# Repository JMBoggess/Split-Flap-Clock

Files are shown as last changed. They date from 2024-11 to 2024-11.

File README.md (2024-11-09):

# Split-Flap-Clock
Clock using a split-flap display

# Background
In December 2023, I bought my first microcontroller. I first began working on a similar project using a split-flap display to show number of instagram followers which I began in February 2024. I began this project in November 2024 seeking to build on what I learned through the previous project. The goal of this project is to create a split-flap display clock with a self-setting time feature. I will be using a Raspberry Pi Pico W microcontroller and 3D printed split-flap displays.

# Components

## 14-Flap Split-Flap Display
The split-flap displays were designed primarily from [Scott Bezek's work](https://github.com/scottbez1/splitflap). My primary alteration is a 14-flap version since I am primarily interested in displaying numbers. I found 14 flaps was a good compromise in reducing the overall dimensions while leaving enough room for certain components (e.g. magnet in the spool section for the Hall sensor). The overall dimensions of each display is:
- Width: 90mm
- Height: 133mm
- Depth: 60mm

## Split-Flap Electronics
- Shift-bit Register (2) - used with the four digit displays
- 28BYJ-48 Stepper Motors (5)
- Driver Boards (5)
- Hall Monitors (5)

## LED
Used to indicate program status
- 1 LED
- 220 Ohm resistor

## Buttons
Allows user to interact with the clock
- 2 buttons
  - Control Configuration mode
  - Manually run NTP Time Update mode

## Slide Switch
Used as an on/off switch

# Source Code

## Events

| Event | Description |
| --- | --- |
| Startup | When the clock is turned on, program execution begins. If enabled in configuration, NTP Time Update mode is executed. Display Update mode is then executed. |
| Config Button Click | A short button press places the clock in Configuration mode. A long button press exits configuration mode. Configuration mode can also be exited in the website |
| Set Date Time Click | A short button press manually starts the Set Date Time mode. A long button press cancels this mode. |
| Set Date Time Timer | Every hour, the clock automatically starts the Set Date Time mode. |

## Modes

### Configuration Mode
The clock is set as an Access Point (AP) allowing users to connect using wi-fi. The user connects with a web browser allowing them to perform the following actions:
- Setup wi-fi connection allowing the clock to connect to their home wi-fi for internet access to set the date and time
- Manually set the date and time of the clock
- View log files for troubleshooting issues
- Exit configuration mode

### Set Date Time Mode
If configured, the clock connects to the internet and updates the date and time using the [Network Time Protocol](https://en.wikipedia.org/wiki/Network_Time_Protocol) (NTP). The clock then runs the Display Update mode.
- This mode will automatically run every hour.
- Users can also click a button to run this mode at any time.

### Display Update Mode
The clock updates the split-flap displays to show the date and time. This mode executes:
- Automatically every minute
- After manually setting the date and time in Configuration mode
- The last step of the Set Date Time mode

## LED Indicator

| Light | Description |
| --- | --- |
| Solid On | The clock is in Set Date Time mode |
| Steady Blinking | The clock is in Configuration mode |
| Four-Pulse Rapid Blinking | An error occurred, view the log for details. The light blinks rapidly four times with a pause and then repeats several times before shutting off |

## Note about Chat GPT
I did not use Chat GPT or any other generative AI (GenAI) to produce any of the code. While I am not opposed to the use of GenAI as a programer, I believe it should be used as a supplemental reference and not in place of learning how to program.

# Notes
- TODO: Determine how to make the program start on power-up

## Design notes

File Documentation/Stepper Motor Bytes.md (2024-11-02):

# Stepper Motor Bytes
Turning a stepper motor effectively involves setting the polarity of two magnets. This is done by turning on or off four poles. There is a sequence of four steps in changing these polarities which results in turning the motor. These four on/off settings can be expressed in binary as follows.

| 8 | 4 | 2 | 1 | Integer | Step |
| --- | --- | --- | --- | --- | --- |
| 0 | 0 | 1 | 1 | 3 | 1 |
| 0 | 1 | 1 | 0 | 6 | 2 |
| 1 | 1 | 0 | 0 | 12 | 3 |
| 1 | 0 | 0 | 1 | 9 | 4 |

For the split-flap display, the motor needs to be run in reverse sequence: `9 > 12 > 6 > 3`. 74HC595 Shift Registers are used to control two split-flap displays. The Shift Regsiters are daisy chained to reduce the number of GPIO pins used on the Raspberry Pi Pico W. These Shift Registers output 8-bit information. With each step, both split-flap displays may or may not need to be moved forward. To determine the byte (8-bit) to send to each Shift Register, the following table was used to derive sequence numbers. A display which does not need to move is denoted with a zero in the Step column.

| 128 | 64 | 32 | 16 | 8 | 4 | 2 | 1 | Integer | Display 1 Step | Display 2 Step |
| --- | --- | --- | --- | --- | --- | --- | --- | --- | --- | --- |
| 1 | 0 | 0 | 1 | 1 | 0 | 0 | 1 | 153 | 4 | 4 |
| 1 | 1 | 0 | 0 | 1 | 1 | 0 | 0 | 204 | 3 | 3 |
| 0 | 1 | 1 | 0 | 0 | 1 | 1 | 0 | 102 | 2 | 2 |
| 0 | 0 | 1 | 1 | 0 | 0 | 1 | 1 | 51 | 1 | 1 |
| 1 | 0 | 0 | 1 | 0 | 0 | 0 | 0 | 144 | 4 | 0 |
| 1 | 1 | 0 | 0 | 0 | 0 | 0 | 0 | 192 | 3 | 0 |
| 0 | 1 | 1 | 0 | 0 | 0 | 0 | 0 | 96 | 2 | 0 |
| 0 | 0 | 1 | 1 | 0 | 0 | 0 | 0 | 48 | 1 | 0 |
| 0 | 0 | 0 | 0 | 1 | 0 | 0 | 1 | 9 | 0 | 4 |
| 0 | 0 | 0 | 0 | 1 | 1 | 0 | 0 | 12 | 0 | 3 |
| 0 | 0 | 0 | 0 | 0 | 1 | 1 | 0 | 6 | 0 | 2 |
| 0 | 0 | 0 | 0 | 0 | 0 | 1 | 1 | 3 | 0 | 1 |

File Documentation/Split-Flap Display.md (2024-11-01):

# Split-Flap Displays
The split-flap displays were designed primarily from [Scott Bezek's work](https://github.com/scottbez1/splitflap).

## Overall Dimensions
A single display has the following dimensions:
- Width: 90mm
  - 3D Printed Box: 69mm
- Height: 133mm
- Depth: 60mm
  - An additional 5-15mm is needed for wire management

## 14 Flaps
The original display by Scott Bezek contains 40 flaps. I chose to reduce this as I am primarily interested in display digits. Reducing the number of flaps reduces the dimensions of various parts. In order to retain enough space for some components (such as the magnet used by the Hall sensor), I found I needed a minimum of 14 flaps.

The 14 Flaps for the primary clock display include:
- Digits 0-9
- Comma `,`
- Semicolon `:`
- Exclamation Mark `!`
- Blank

A single 14-flap display is also used for day-of-week and time-of-day, including:
- Sun - Sat displayed on the top
- AM or PM displayed on the bottom

## 3D Printed Components

### Dimensions
Unless otherwise specified, all components were made to be 3mm thick.

- Top: 42mm x 69mm
  - Includes insert tabs (3mm on either side): 69mm - 6mm = 63mm
  - Includes two vertical screw-hole tabs for attaching to a face plate
    - These are both 10mm x 10mm
    - Component overall height is 13mm (3mm thickness + 10mm tabs)
- Base: 52mm x 69mm
  - Includes insert tabs (3mm on either side): 69mm - 6mm = 63mm
  - Includes two screw-hole tabs for attaching to a base
    - Both are 10mm x 10mm
    - 52mm - 10mm = 42mm
- Left Side: 42mm x 126mm
  - Motor hole center:
    - 9mm from edge
    - 63mm from bottom
- Right Side: 42mm x 126mm
  - Hole for spindle (opposite motor) same as Left Side (9mm from edge; 63mm from bottom)
  - Bottom flap restraint: begins 12mm from bottom, 4mm from either side
- Spool Left: 31mm diameter
  - Flap holes center: 9mm from center (2.5mm diameter)
- Spool Right: 31mm diameter
  - Flap holes center: 9mm from center (2.5mm diameter)
  - Magnet hole for Hall sensor: 12.5mm from center (3.2mm diameter)
    - Flap "0" should be located directly across from this hole
- Spool Box: 4 parts - 5mm x 55mm each
  - 2mm thick
  - Used for stability and assembly
- Axel Holder: 7mm x 7mm
  - 3.2mm thick
  - Used on right-side to hold axel screw (opposite motor)
- Face: 69mm x 30mm
  - This piece was used for testing, final wood box will act as face
  - Distance between holes: 31.5mm

In addition to the above components, I 3D printed a series of jigs
- Jig Flap Split: 60mm x 46mm
  - Used to score/cut cards in half to make flaps
  - 1mm thick lip 3mm wide to create a ledge against which the cards are placed
  - Results in flaps 43mm heigh (46mm - 3mm ledge)
- Jig Flap Hole: 40mm x 29mm
  - L-shaped jig, placed on the edge of a flap against which the hole punch is placed to cut the slot in the flap
- Jig Flap Hold: 37mm diameter
  - Used to hold flap cards in place while assemblying the spool
  - 33mm internal diameter

### Development
- I used OpenSCAD v2021.01 for 3D modeling
- STL files were then exported from OpenSCAD
- Creality Slicer v4.8.2 was used to encode the STL file to GCODE for the 3D printer
  - Some components were combined for printing into a single GCODE file
  - To create files:
    - Open STL file(s)
    - If desired, duplicate components (right-click)
    - Click Slice button
    - Red areas indicate problems (where model needs support)
    - Save the file as a GCODE file
    - Copy to sd card to load to Ender printer

### Card Layout
The following table depicts the card layout for the digits and day-of-week (DOW) and time-of-day (TOD) display.
- Flap - The visible flap displayed to the user (consists of different cards making up the Top and Bottom of the display)

| Flap | Position | Card | Digits | DOW/TOD |
| --- | --- | --- | --- | --- |
| 1 | Top | 1 | 0 | SUN |
| 1 | Bottom | 14 | 0 | AM |
| 2 | Top | 2 | 1 | SUN |
| 2 | Bottom | 1 | 1 | PM |
| 3 | Top | 3 | 2 | MON |
| 3 | Bottom | 2 | 2 | AM |
| 4 | Top | 4 | 3 | MON |
| 4 | Bottom | 3 | 3 | PM |
| 5 | Top | 5 | 4 | TUE |
| 5 | Bottom | 4 | 4 | AM |
| 6 | Top | 6 | 5 | TUE |
| 6 | Bottom | 5 | 5 | PM |
| 7 | Top | 7 | 6 | WED |
| 7 | Bottom | 6 | 6 | AM |
| 8 | Top | 8 | 7 | WED |
| 8 | Bottom | 7 | 7 | PM |
| 9 | Top | 9 | 8 | THU |
| 9 | Bottom | 8 | 8 | AM |
| 10 | Top | 10 | 9 | THU |
| 10 | Bottom | 9 | 9 | PM |
| 11 | Top | 11 |  | FRI |
| 11 | Bottom | 10 | , | AM |
| 12 | Top | 12 | : | FRI |
| 12 | Bottom | 11 | : | PM |
| 13 | Top | 13 | ! | SAT |
| 13 | Bottom | 12 | ! | AM |
| 14 | Top | 14 |  | SAT |
| 14 | Bottom | 13 |  | PM |

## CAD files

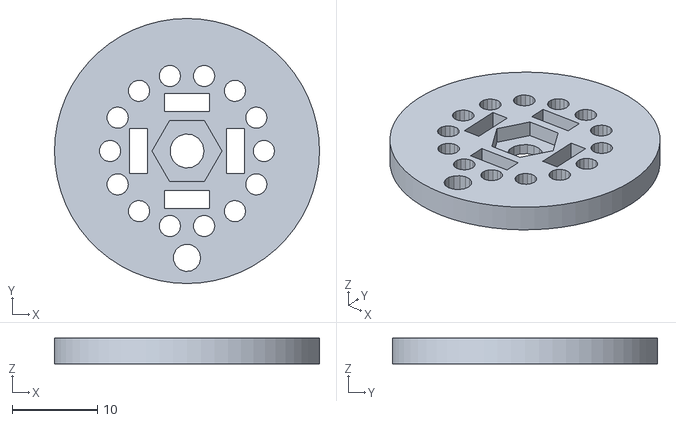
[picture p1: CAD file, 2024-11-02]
Split Flap/STL/spool-right.stl
31.0 x 31.0 x 3.00

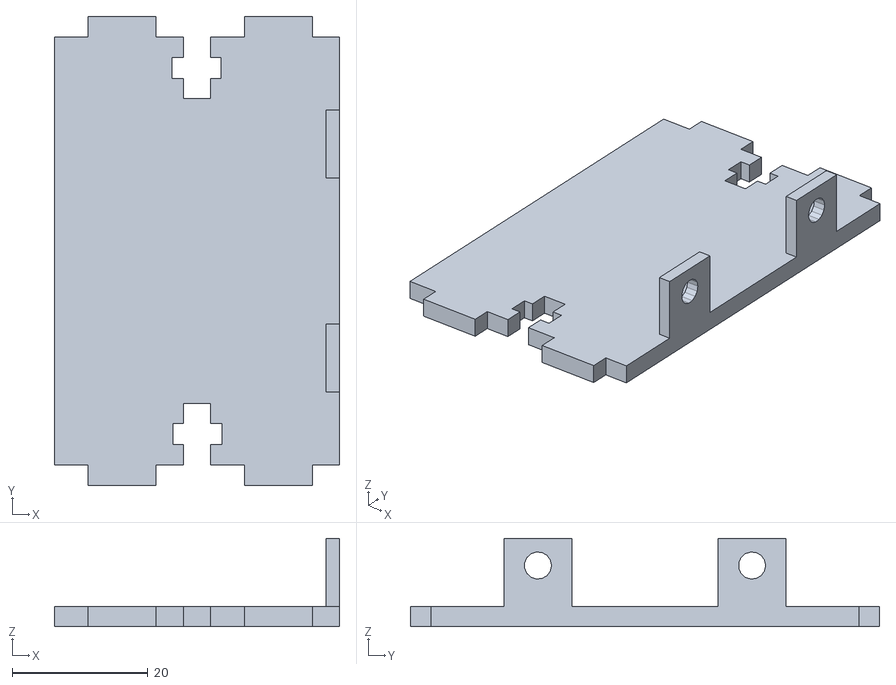
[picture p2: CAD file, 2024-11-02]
Split Flap/STL/top.stl
42.0 x 69.0 x 13.0

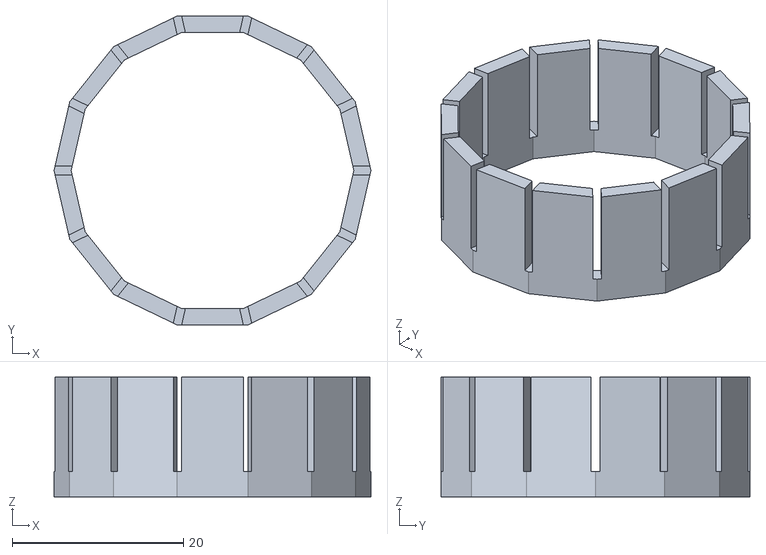
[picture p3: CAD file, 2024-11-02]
Split Flap/STL/jig-flap-hold.stl
37.0 x 36.1 x 14.0

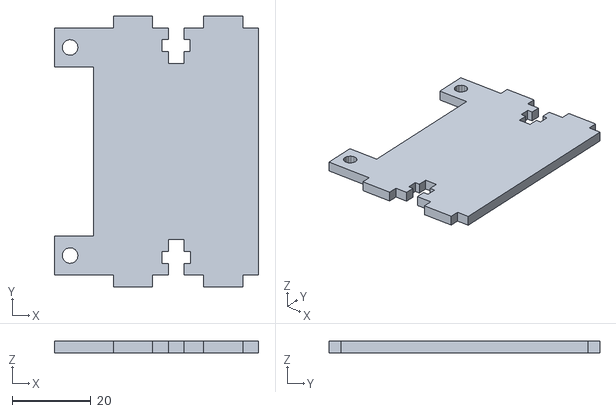
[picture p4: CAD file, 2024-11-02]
Split Flap/STL/base.stl
52.0 x 69.0 x 3.00

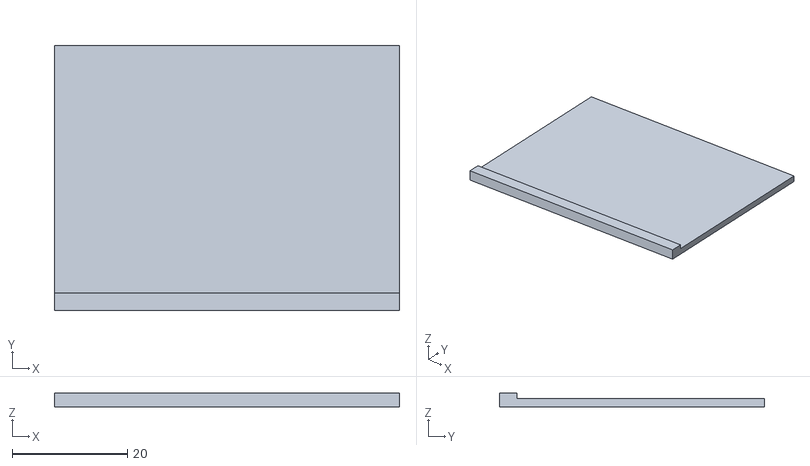
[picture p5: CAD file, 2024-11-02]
Split Flap/STL/jig-flap-split.stl
60.0 x 46.0 x 2.50

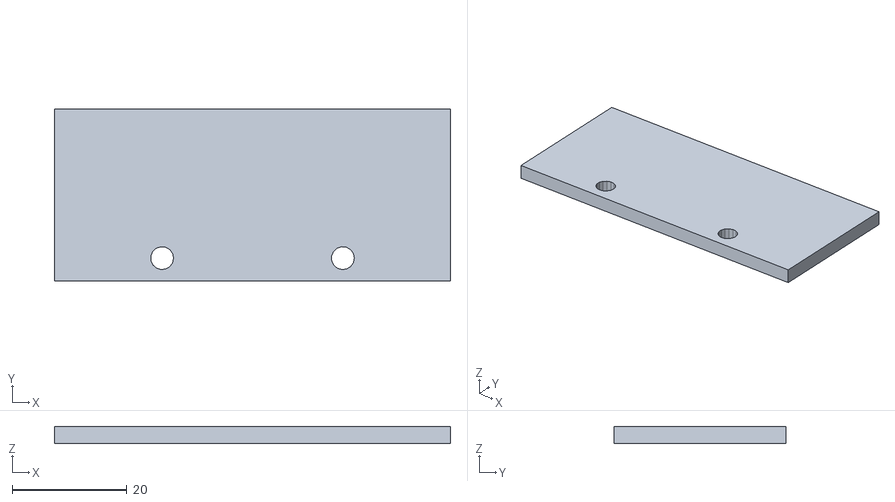
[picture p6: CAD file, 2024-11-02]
Split Flap/STL/face.stl
69.0 x 30.0 x 3.00

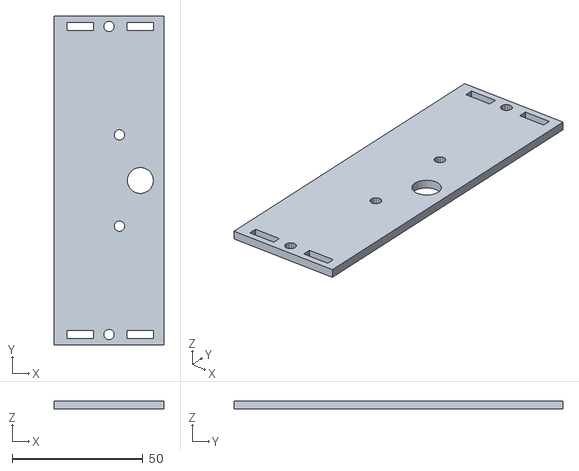
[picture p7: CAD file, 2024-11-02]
Split Flap/STL/left-side.stl
42.0 x 126.0 x 3.00

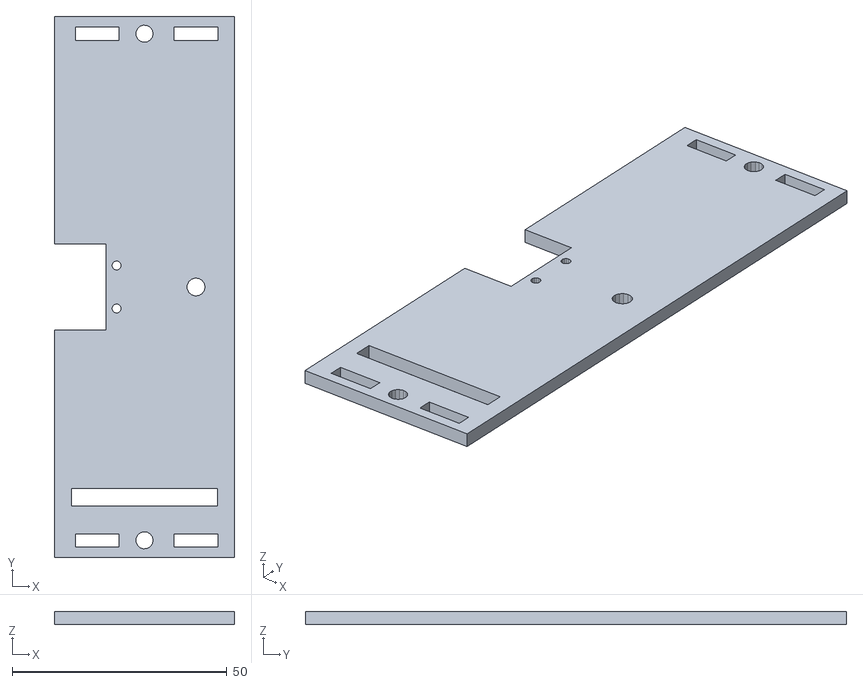
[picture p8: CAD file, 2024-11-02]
Split Flap/STL/right-side.stl
42.0 x 126.0 x 3.00

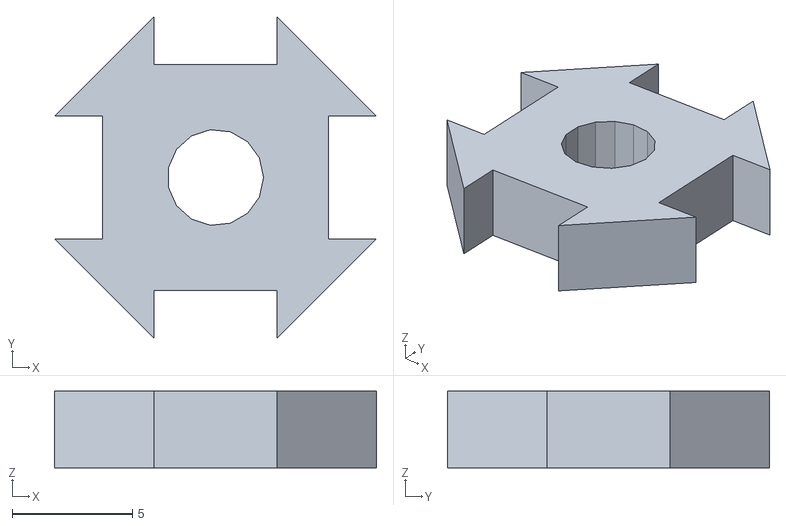
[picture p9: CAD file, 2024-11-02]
Split Flap/STL/axel-holder.stl
13.4 x 13.4 x 3.20

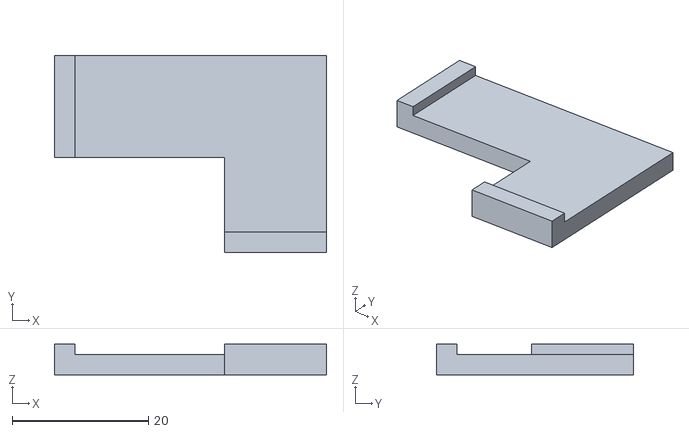
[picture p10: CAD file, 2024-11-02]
Split Flap/STL/jig-flap-hole-v3.stl
40.0 x 29.0 x 4.50

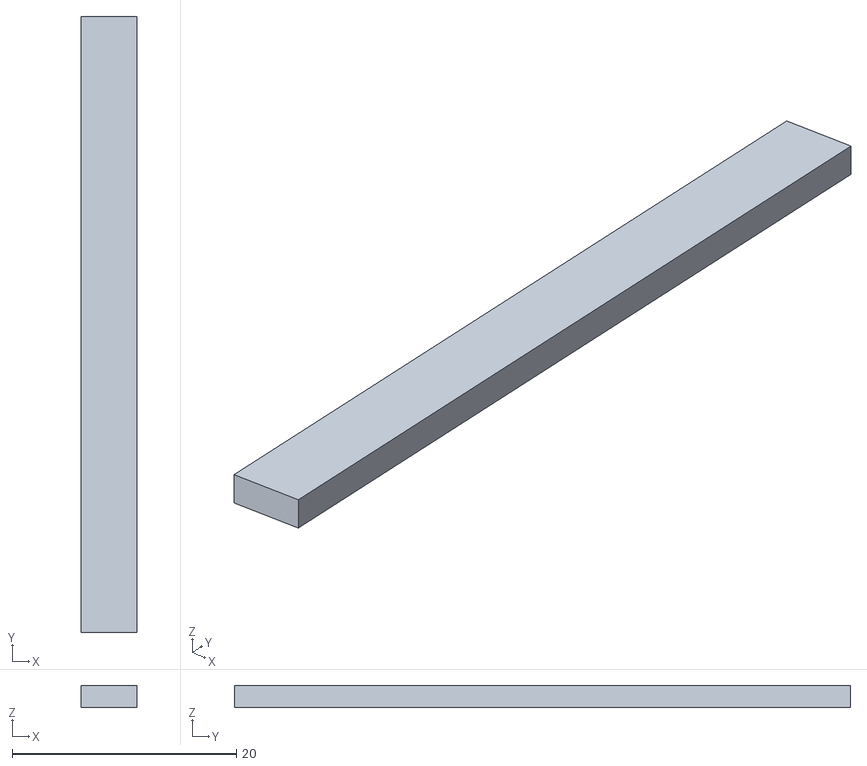
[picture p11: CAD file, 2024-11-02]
Split Flap/STL/spool-box.stl
5.00 x 55.0 x 2.00

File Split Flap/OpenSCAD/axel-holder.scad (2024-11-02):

// Used a 16mm long screw

module squares() {
    square(9.4, center=true);
    translate([4.625, 4.625])
        square(4.15, center=true);
    translate([4.625, -4.625])
        square(4.15, center=true);
    translate([-4.625, 4.625])
        square(4.15, center=true);
    translate([-4.625, -4.625])
        square(4.15, center=true);
}

module squares_cut() {
    // Subtract out triangles for holes
    difference() {
        squares();
        
        translate([6.7, 6.7])
            rotate([0,0,45])
                square(5.87, center=true);
        translate([6.7, -6.7])
            rotate([0,0,45])
                square(5.87, center=true);
        translate([-6.7, 6.7])
            rotate([0,0,45])
                square(5.87, center=true);
        translate([-6.7, -6.7])
            rotate([0,0,45])
                square(5.87, center=true);
    }
}

module axel_holder_2d() {
    difference() {
        squares_cut();
        circle(r=2, $fn=15);
    }
}

module axel_holder() {
    linear_extrude(3.2) {
        axel_holder_2d();
    }
}

axel_holder();

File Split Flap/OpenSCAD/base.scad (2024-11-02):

module nut_hole() {
    // Shape for inserting the screw
    translate([-2, 0])
        square([4,3]);
    
    // Shape for the nut
    translate([-3.55,3])
        square([7.2,3.1]);
    
    // Space for screw past nut
    translate([-2, 6.1])
        square([4, 3]);
}

module squares() {
    // Main squares for base
    translate([0, 3])
        square([42,63]);
    
    // Tabs left
    translate([5,0])
        square([10,3]);
    translate([28,0])
        square([10,3]);
    
    // Tabs right
    translate([5,66])
        square([10,3]);
    translate([28,66])
        square([10,3]);
    
    // Wood mount squares
    translate([-10,3])
        square([10,10]);
    
    translate([-10,56])
        square([10,10]);
}

module base_2d() {
    
    difference() {
        // Primary Shape
        squares();
        
        // Screw/Nut hole left
        translate([21,3])
            nut_hole();
        
        // Screwn/Nut hole right
        translate([21,66])
            rotate([0,0,180]) {
                nut_hole();
            };
        
        // Wood mount screw holes
        translate([-6, 8])
            circle(r=2, $fn=15);
        translate([-6, 61])
            circle(r=2, $fn=15);
    }
}

module base() {
    linear_extrude(3) {
        base_2d();
    };
}

base();
//nut_hole();

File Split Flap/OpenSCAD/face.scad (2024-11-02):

module face_2d() {
    difference() {
        // Main shape
        square([69,30]);
        
        // Screw holes
        translate([18.75, 4])
            circle(r=2, $fn=15);
        
        translate([50.25, 4])
            circle(r=2, $fn=15);
    }
}

module face() {
    linear_extrude(3) {
        face_2d();
    }
}

face();

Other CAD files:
Split Flap/STL/spool-left.stl
Split Flap/OpenSCAD/jig-flap-hold.scad
Split Flap/OpenSCAD/jig-flap-hole-v3.scad
Split Flap/OpenSCAD/jig-flap-split.scad
Split Flap/OpenSCAD/left-side.scad
Split Flap/OpenSCAD/right-side.scad
Split Flap/OpenSCAD/spool-box.scad
Split Flap/OpenSCAD/spool-left.scad
Split Flap/OpenSCAD/spool-right.scad
Split Flap/OpenSCAD/top.scad

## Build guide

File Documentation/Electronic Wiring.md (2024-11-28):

# Electronic Wiring

## Disclaimer: I am not an electrical engineer
Yes, it will be obvious as you look at the diagrams on this page... I know very little about electrical engineering. I spent some time digging into electrical diagraming and found out:
1. Learning to read and create these diagrams is a large undertaking.
2. Diagraming can be a very sensitive topic amoung electrical engineers.

Part of the purpose of this project was to be my first exposure to the world of electrical engineering. I have learned a great deal during this journey and gained a greater appreciation for what I do not know. Learning any topic involves moving through four stages:
1. Unconcious Ignorance - simply being unaware of the topic entirely
2. Concious Ignorance - becoming aware of the topic including the breadth and depth and your ignorance about the topic (I'm here)
3. Concious Knowledge - gaining knowledge about the topic, yet having to expend a great deal of mental effort to recall and use that knowledge
4. Unconcious Knowledge - where knowledge of the topic is "second nature"

Before beginning I knew I was in step 1 and my goal was to move to step 2. So please treat the below with a great deal of grace. I am excited about what I have been able to do in this project and that motivation will help me continue to pursue learning in the topic.

# Testing Diagram
The following is a functional diagram of how I connected the electronic components to test the overall functionality and code.
- I used Draw.io to create the diagram
- My goal was to make a diagram legible to the layperson (me) as a guide

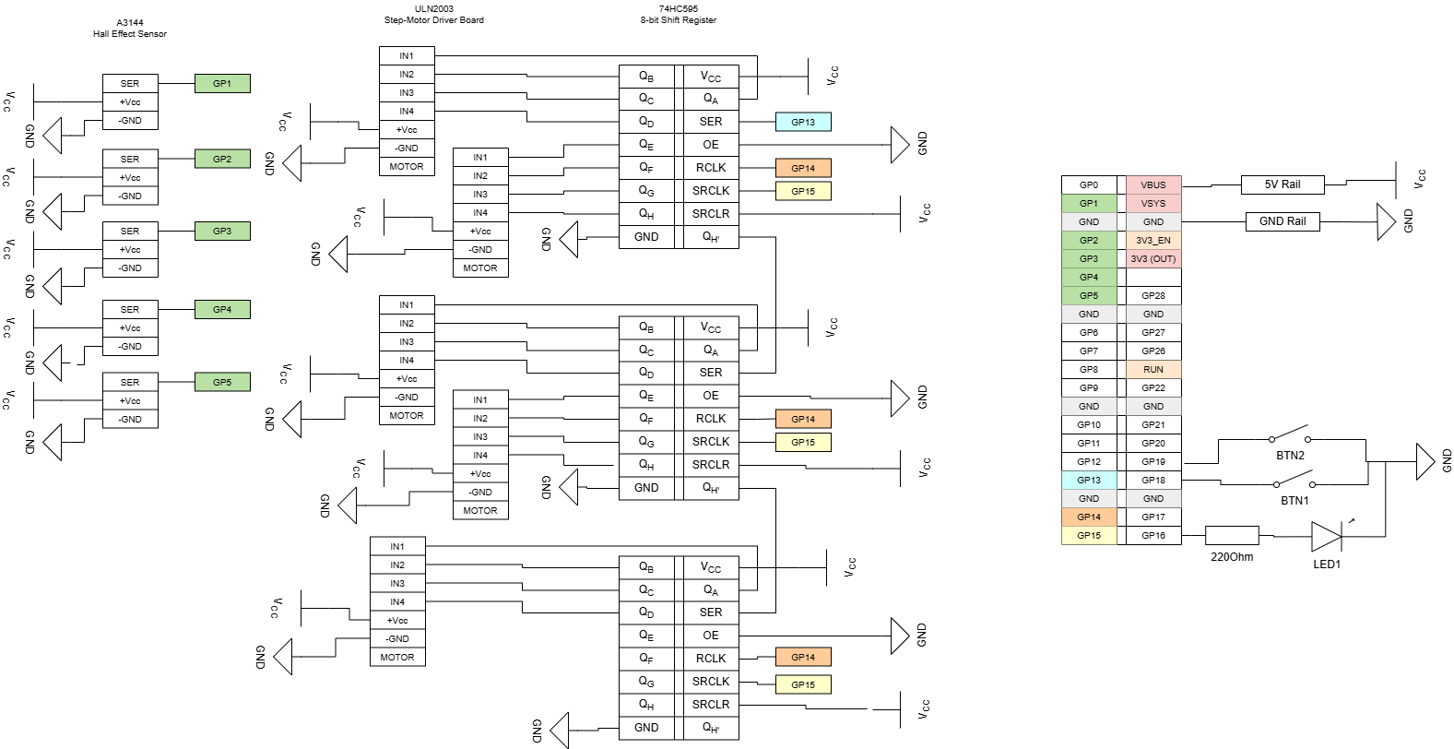
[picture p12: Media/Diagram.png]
Wiring Diagram


## Observations

### Power
For testing purposes, the Pico W is connected to the computer through a USB cable. All Vcc components are indications of what is connected to the power rail (GND indicates the Ground Rail).
- I will need to determine how to properly power the final product
- HC595 shift registers can also be powered by 3.3V

### GPIO (General Purpose Input/Outuput)
All pins used on the Pico W are GPIO. I color-coded the pins to make it easier to identify what is plugged in and how many pins will be used on the Pico W.
- I used 8-bit shift registers daisy-chained together to reduce the number of pins used
- There are a total of 11 pins that will be used by the final product

## Shift Registers
There are a total of three 8-bit shift registers used. Each display requires four bits so two displays can be driven from one register. The last register has only one display so the remaining four bits are not used. Pin configuration involves:
| Pin(s) | Connection |
| --- | --- |
| QA, QB, QC, QD | One step-motor driver board |
| QE, QF, QG, QH | Another step-motor driver board |
| GND (Ground) | Ground rail |
| OE (output enabled) | Ground rail, i.e. register output is always enabled |
| VCC | SysBus 5 volts |
| SRCLR (shift register clear) | Sysbus 5 volts, i.e. register is immediately cleared each time |
| SRCLK "clock" (shift register clock) | GPIO pin - all shift registers use the same pin |
| RCLK "latch" (storage register clock) | GPIO pin - all shift registers use the same pin |
| SER (serial input) | First shift register is connected to GPIO pin, subsequent go from this pin to the GH' pin of the parent register |
| QH' | Used in daisy chain, last register will not use this pin, recieves the SER connection from a child register |

## Hall Effect Sensors
Each display uses a Hall Effect Sensor to read a magnet connected to the split-flap wheel indicating which flap is the "home" position. Each are connected to a separate GPIO pin on the Pico W. In code, Pin.PULL_UP is used to eliminate the need for a resistor.

# Wiring Test
I used the above to test all wiring and code using a breadboard. I was able to successfully run the code as expected and set the time.
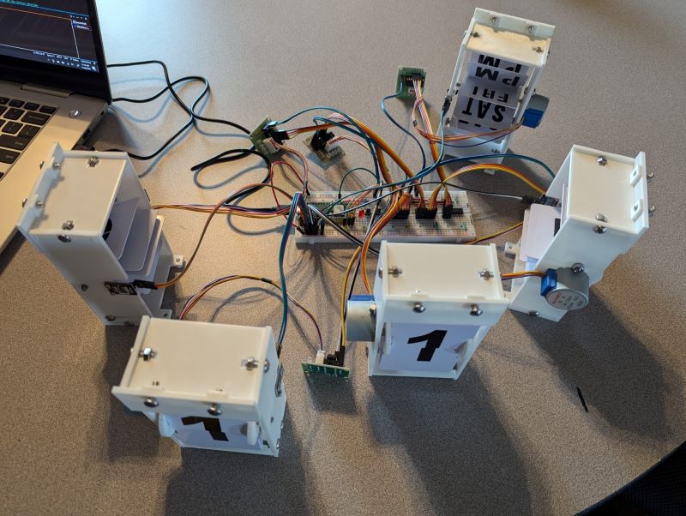
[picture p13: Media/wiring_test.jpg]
Wiring Test


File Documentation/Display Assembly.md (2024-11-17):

# Display Assembly
The following provides information on how to assemble a split-flap display.

## Parts

### 3D Printed Parts
- Left side
- Right side
- Split-flap cards (see below for parts list)
- Spool-box (4 long rectangles)
- Axel-holder
- Left and Right Spools
- Top
- Bottom/Base
- Face (for testing purposes)
- Jigs
  - Split - for cutting cards in half
  - Hole - for punching out holes on side of cards
  - Hold - for holding cards in place during assembly
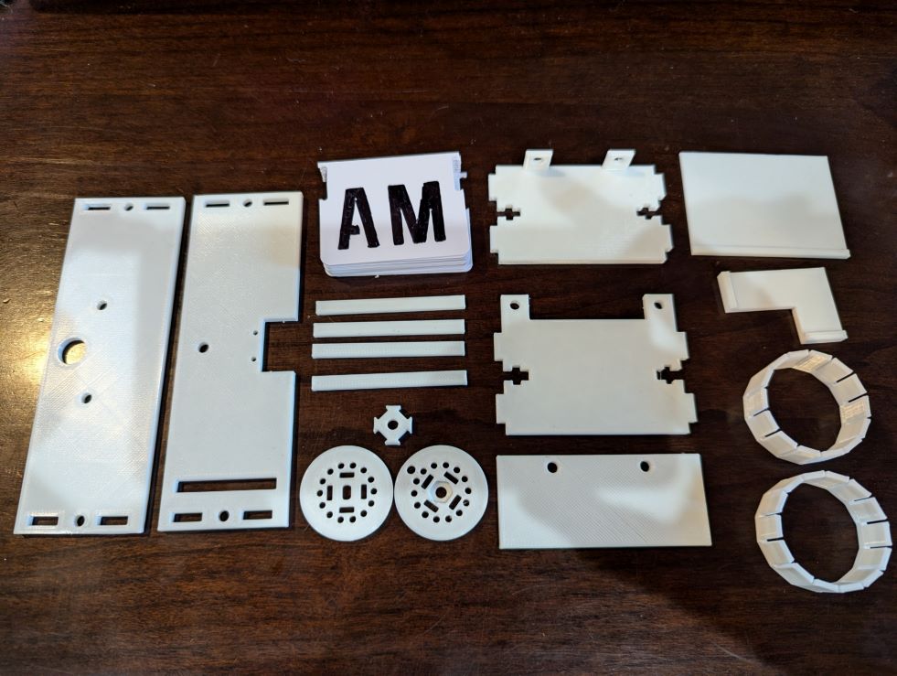
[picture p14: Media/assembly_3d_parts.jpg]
3D Printed Parts


### Split-flap cards
- [CR80 30 mil PVC cards](https://a.co/d/4AWDuIj) (commonly used for badges)
- [Card Slot Hole Punch](https://a.co/d/3zdMEoE)
- X-acto knive
- Permenant marker
- Stencils
  - [3-inch letters and numbers](https://a.co/d/gLgWajX) (used for digit display)
  - [1/2 and 3/4 inch letters](https://a.co/d/g1cRKLc) (used for AM/PM and days of week)
- Rubbing alchohol
- Masking tape or painters tape
- 3D printed Jigs (as listed above)
  - Split - for cutting cards in half
  - Hole - for punching holes or slots in side of card
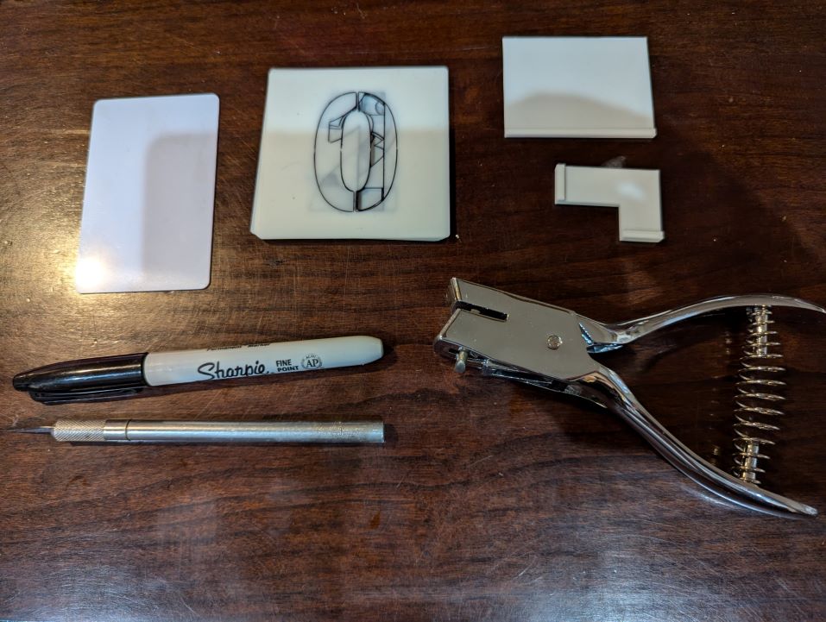
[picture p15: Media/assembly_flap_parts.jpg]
Split-Flap Card Parts


### Hardware
- Hex Drive Button Socket Cap Screws
  - [M4 x 8mm](https://a.co/d/axGSh9M) (qty: 2)
  - [M4 x 10mm](https://a.co/d/h3HqGNw) (qty: 4)
    - Optionally: 2 additional for face plate
  - [M4 x 16mm](https://a.co/d/axGSh9M) (qty: 2)
- Phillips Head Machine Screws
  - [M2 x 6mm](https://a.co/d/1rp4N2g) (qty: 2)
- [M4 Nuts](https://a.co/d/0MgO0n8) (qty: 8)
  - Optionally: 2 additional for face plate (permenant assembly option)
- [M2 Nuts](https://a.co/d/1rp4N2g) (qty: 2)

### Electronics
- [Hall Effect Sensor](https://a.co/d/9E8ezPd) (3144E A3144)
- [3mm Magnet](https://a.co/d/gIFRxZn)
- [ULN2003 Driver Board](https://a.co/d/5FAjnlJ)
- [28BYJ-48 Stepper Motor](https://a.co/d/5FAjnlJ)
- [Wire](https://a.co/d/huoj8Pj)
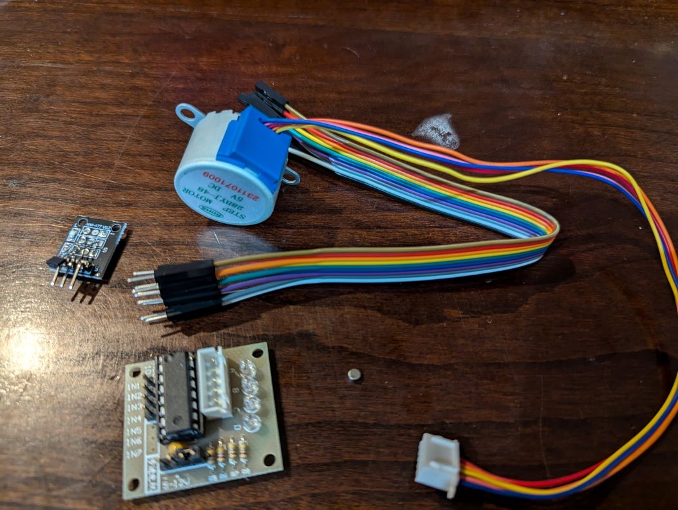
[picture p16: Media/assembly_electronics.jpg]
Electronic Parts


### Tools and Other
- Files
  - Used to file 3D printed parts as needed
- Allen wrench
- Small phillips screw driver

## Split-Flap Cards
- Place a card under the "Split" jig so that the lip of the jig is on the outside of the card
  - The jig falls at the middle of the card
- Use an x-acto knife to score a line down the middle of the card at the jig
- Bend the card back and forth until it breaks along the score line
  - I also found it useful to bend the card, turn it over, and score the opposite side of the card along the bend line
- On either side of the card, use the "Hole" jig to position the Card Slot Hole Punch and punch a slot/hole on either side
  - This will form the small spoke-like sections which can be inserted into the spool holes
  - Use an x-acto knife to clean up the holes as needed
- (Optional) Use rubbing alchohol to clean both sides of the card from any dirt and oils from handling the cards
- Place the desired stencil on the card and fill-in using a permenant marker
  - For digits, the number spans two cut cards (i.e. one full uncut card length)
  - I used painters tape to hold the cards and stencil in place

## Spool Box Assembly

### Install Magnet
Prior to inserting the magnet into the spool (right-side), you must first determine which pole of the magnet is read by the Hall Sensor. For the Hall Sensors I purchased, the sensor head was bent the opposite direction from where it needed to be in the final assembly. As a result, I had to first bend the sensor head away from the pins (where the cables attach). Connect the Hall Sensor to the Pico W and run a script to continuously read. Hold the magnet near the sensor and determine which side results in a positive read (reverse the magnet as needed). Use a marker to place a dot on the side that needs to be read from to ensure proper assembly into the spool.

Pin configuration:
- Minus (-) - ground
- Plus (+) - SysBus (5v) assuming powered by USB
- Serial In (S) - any GPIO port (use Pin.PULL_UP)

Example script:
```python
from machine import Pin
from time import sleep

p = Pin(0, Pin.IN, Pin.PULL_UP)

while True:
    try:
        print(p.value())
        sleep(1)
    except KeyboardInterrupt:
        break
```

Once the correct side is determined, place the magnet in the spool hole with the side you marked facing out. The indent for the nut is the outside of the spool and the same side the hall sensor will be reading the magnet. In some cases, I found I had to use some CA glue to keep the magnet in the spool hole. The below image shows the correct side facing out/up which will be read by the hall sensor.
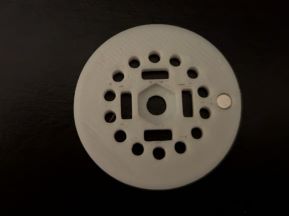
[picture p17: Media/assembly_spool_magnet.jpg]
Spool with magnet


### Spool Lineup
Identify where the holes lineup between the left and right spool. In the below image, on the left, the slots lineup but the holes do not. In the right image, both the slots and holes line up. Place a mark on the spools to identify holes that align. I placed a dot on the holes opposite the magnet as these are the holes for split-flap card zero - the first split-flap card index to be displayed.
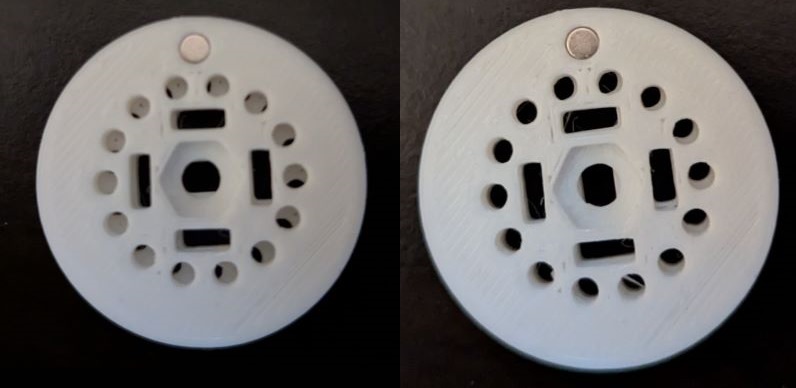
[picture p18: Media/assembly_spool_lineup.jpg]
Spool Hole Lineup


### Axel-Holder
Using an M4 x 16mm screw and nut, attach the axel-holder to the right-spool. The head of the screw will be on the inside (side opposite the inset space for the hex net). Leave the assembly loose to rotate the axel-holder into final position. The screw will be tightened after installing the flaps and spool box components.
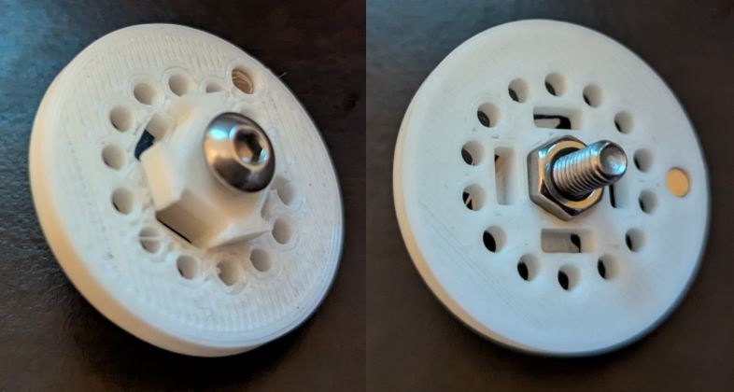
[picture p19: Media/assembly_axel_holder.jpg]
Axel Holder


### Spool Box
Attach all four supports for the spool box to the left spool (non-magnet spool). Push these flush with the outside/bottom of the spool. Push the four supports onto the axel-holder and slightly into the right spool. I loosened the axel-holder screw significantly to push the axel holder as far down into the box as possible. The more space provided to install the flaps the better while simultaneously starting to insert the four supports is optimal. The most difficult part of this assembly is lining up the flaps with the holes while simultaneously pushing the spools onto the spool box supports.

The "spool box" is four support pieces. I am referring to this as the spool box as the original design this is drawn from the four components form an actual box to which the spools sit on either end. In reducing the size of the display, I found it necessary to not make these components meet into a true box. For lack of better term, I am still referring to this as the "spool box".
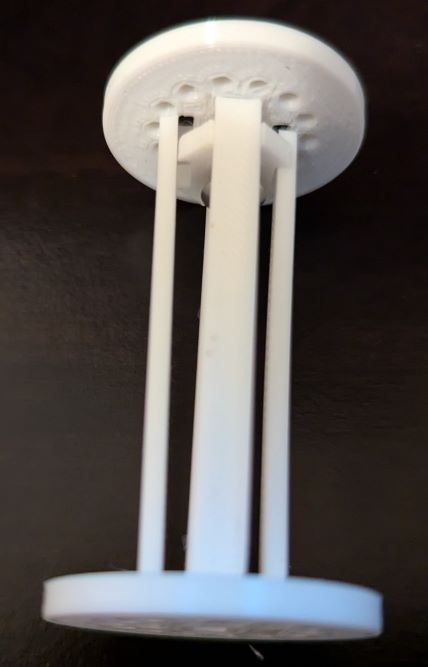
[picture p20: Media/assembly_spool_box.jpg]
Spool Box


### Flap-Spool Assembly
This is the most difficult part of assembly. Place one of the Hold jigs on a work surface. Place the left spool (non-magnet spool) inside the jig. Place the flaps into the left-spool holes using the jig to support the flaps and help keep them aligned. Be sure to start with the desired flap (flap 0) in the holes located opposite the magnet (marked previously during spool lineup). The spool will rotate counter-clockwise from the current viewing position. Flaps should be placed in sequence so they will display in order as the spool turns this direction.
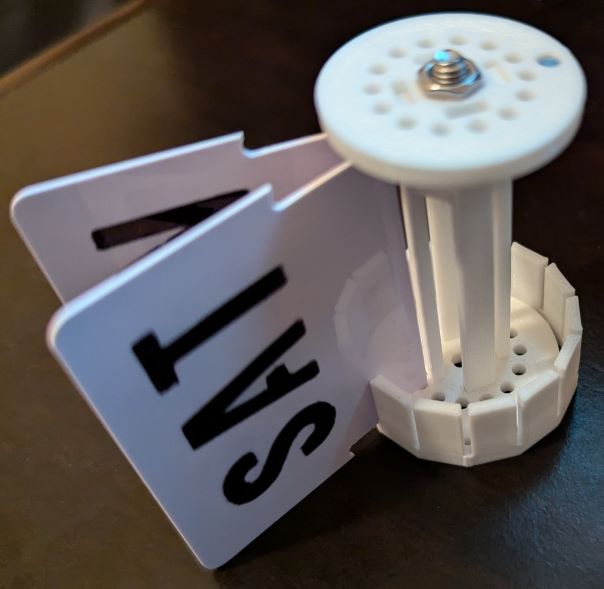
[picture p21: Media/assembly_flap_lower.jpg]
Flap Lower


Once the flaps are inserted securly in the left-spool (on bottom), place another Hold jig on the top to help line up the flaps with the right-spool (on top). Ensure the flaps are in each hole otherwise they will bend when pressing the spools together.
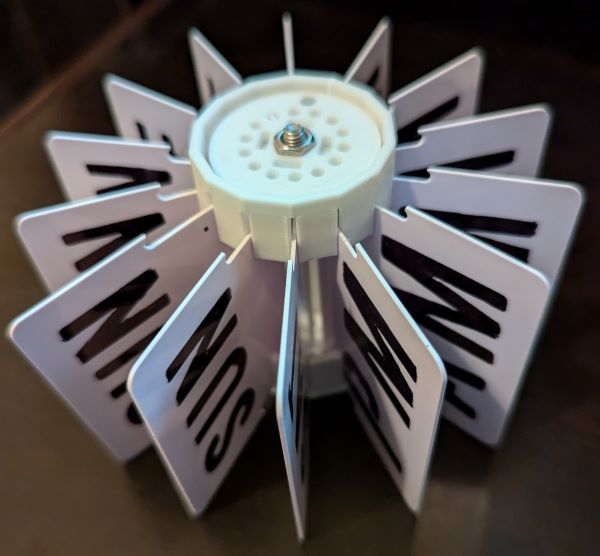
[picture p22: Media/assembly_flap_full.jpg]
Flap Full


Press the right-spool (on top) down to lock the flaps and spool box in place. I worked this in quarter sections, lining up flaps on one side and pressing that side together, turning, and repeating the process back and forth until the spool locked down into place. In the below photo, notice the flap ends are visible through the holes indicating they are in place and not bent inside the spool assembly. You can carefully turn over the assembly with the jigs in place to inspect both ends as needed.
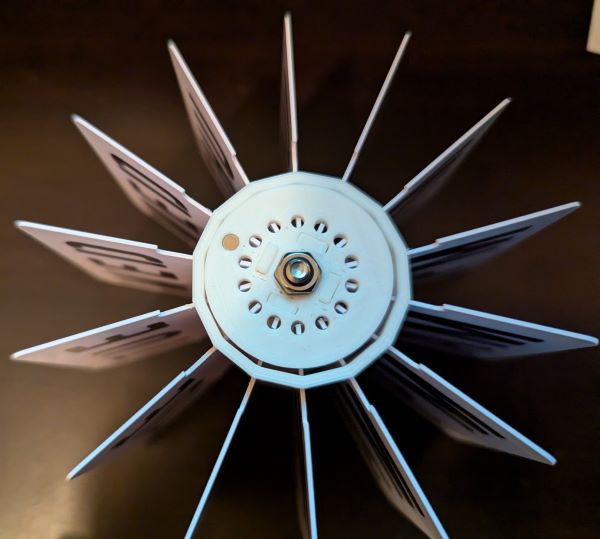
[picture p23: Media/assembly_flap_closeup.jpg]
Flap Close Up


Once all flaps are in place and the spools are pressed down so the spool box support pieces are flush, remove the jigs. Ensure the spool box suppor pieces are not extending beyond the spool (i.e. overtighten) otherwise the flaps will not rotate freely. Use the hex wrench to then tighten the axel-holder screw (insert the hex wrench through the hole of the opposite spool).
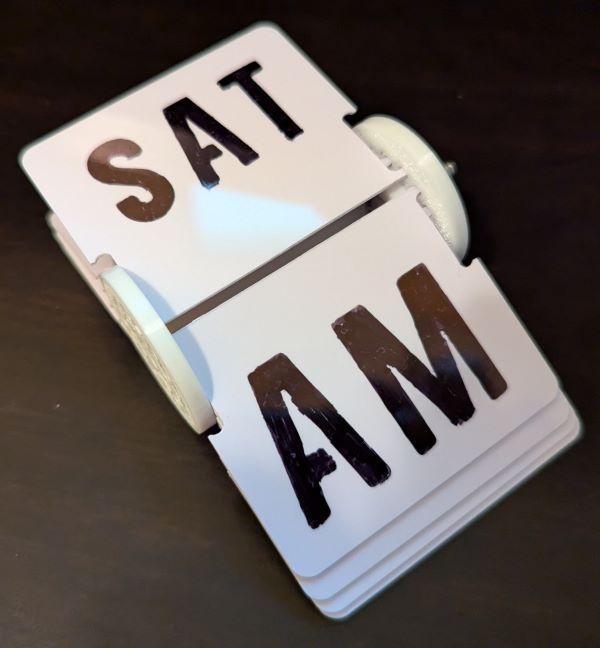
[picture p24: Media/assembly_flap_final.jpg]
Flap Final


## Outer Box Assembly

### Hall Sensor
Install the Hall Sensor on the right side piece using M2 x 6mm screws and nuts. The back of the Hall Sensor board faces the outside of the finished assembled box. Note the slot in the right side piece for the flap-stop screw, this is at the bottom of the finished box. The Hall Sensor should be bent around the plastic so that it will be near the magnet when the spool assembly is added. The below depicts the installed hall sensor on the inside (left image) and outside (right image).
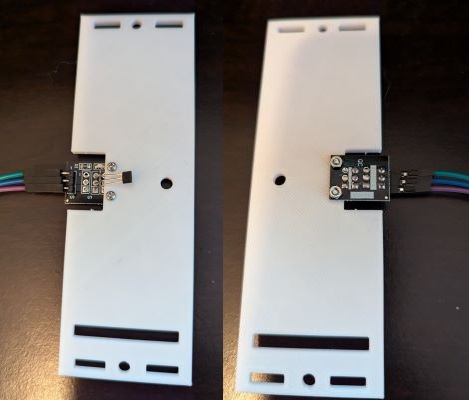
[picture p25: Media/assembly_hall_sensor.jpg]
Hall Sensor


### Step Motor
Install the Step Motor on the left side piece using M4 x 8mm screws and nuts. The hole for the Step Motor is in the center of the left side and so it is reversible. The body of the motor is on the outside of the box. Place the heads of the screws on the inside with the nuts on the outside of the box (next to the body of the motor).
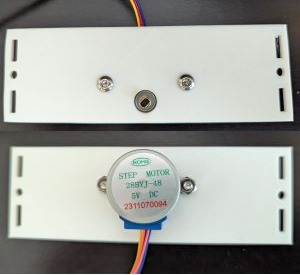
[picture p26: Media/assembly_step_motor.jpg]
Step Motor


### Top and Base Preparation
Push four nuts into the Top and Base components. There are slots for the nuts. The flat part of the nuts should be perpendicular to the thickness of the plates. If necessary, use files to widen the slots for easier assembly. I also used the shaft of the allen wrench in the nut hole to push against and alternatively used a scrap plastic piece to push on top of the nuts.
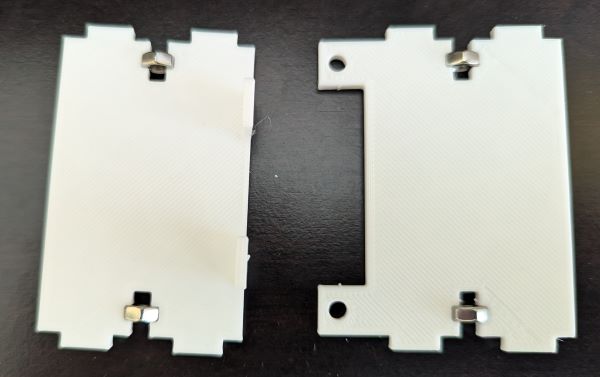
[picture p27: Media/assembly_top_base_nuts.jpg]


### Left Side and Flap-Spool
Push the assemblyed Flap-Spool assembly onto the step motor of the left side. Leave a gap between the side panel and the flap spool so it can rotate freely avoiding the screw heads.
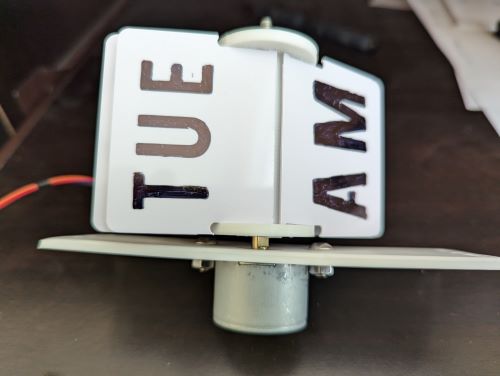
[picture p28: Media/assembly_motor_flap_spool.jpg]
Step Motor and Flap-Spool


### Top, Base, and Left Side
Attach the Top and Base to the left side using four M4 x 10 screws. The vertical tabs on the Top should be facing the front of the assembled box. The horizontal tabs of the base should be facing the back of the assembled box. It may be necessary to use a file on the tabs of the Top and Base. The image below is shown from the front.
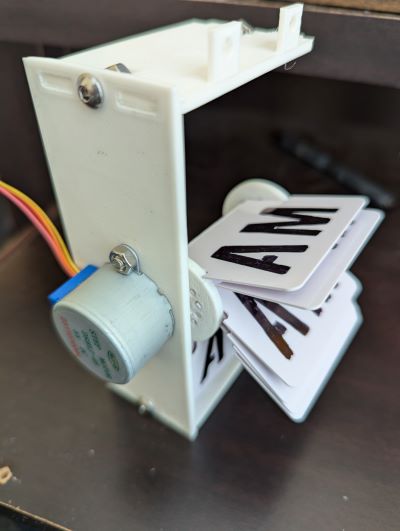
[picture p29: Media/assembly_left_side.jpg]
Left Side with Top and Base


### Right Side
Attach the right side to the Top and base with the screw on the spool protruding through the side.

### Flap Stop Screw
Insert an M4 x 16mm screw through the flap stop slot on the right side panel. Attach with a nut. I found placing this screw at the front of the slot performed the best. It can be adjusted during testing of the display.
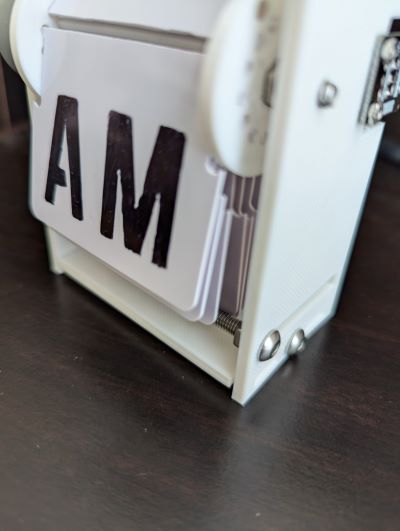
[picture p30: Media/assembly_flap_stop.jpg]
Flap Stop Screw


### Face Plate
Attach the face plate using two M4 screws. This is intended for testing purposes as the final box will have a wood trim to act as the face plate. If desired, this face plate can be used for final production in which case secure the screws with nuts.

## Final Display
The final display is now ready for testing.

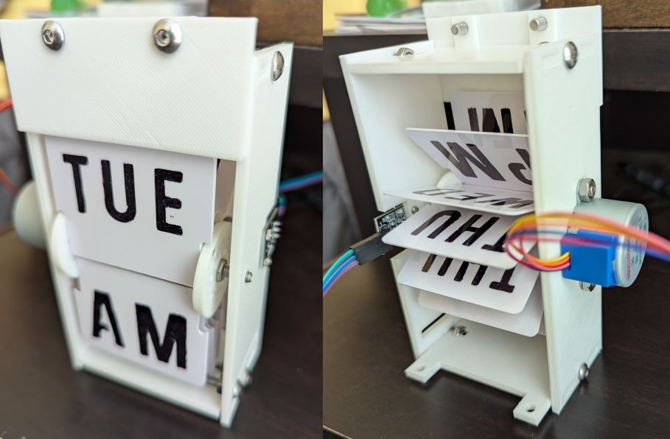
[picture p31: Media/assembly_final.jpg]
Final Assembly


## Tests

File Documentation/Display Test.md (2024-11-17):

# Split-Flap Display Test
After assemblying a split-flap display, use the test_display python file to test the display and take readings which can be used in program configuration.

## Script Configuration

### Flap Values
The script assumes a 14-flap design. Ensure the proper flap values are set (__init__ function of the Digit class):

```python
# Array of flaps - first value (index: 0) should be the Home character
# Version 1: digits
# self.flap_values = ['0','1','2','3','4','5','6','7','8','9',',',':','!',' ']
# Version 2: day-of-week (0=Sun) and meridem
self.flap_values = ['0-AM','0-PM','1-AM','1-PM','2-AM','2-PM','3-AM','3-PM','4-AM','4-PM','5-AM','5-PM','6-AM','6-PM']
```

### Home Reads
Home Reads are the number of positive magnet reads by the Hall Sensor to set as the home or zero-index position of the display. Use the hall_readings method (described below) to assist with setting this value. This value should be consistent for all displays in the final clock and the Digit class in the clock's code should be updated.

```python
self.home_reads = 90
```

### Pin Configuration
After the Digit class code and all testing methods, ensure the correct GPIO pin numbers are set to create the digit object.

```python
digit = Digit([2,3,4,5], 0)
```

## Tests
The script contains tests at the bottom of the script. Comment/uncomment sections as appropriate to execute a test.

### One Full Rotation
This test slows rotates the display one full revolution. Use cases:
- Ensure the display can rotate freely
- Ensure flaps do not stick
  - If the spools are too tight, flaps may not fall freely when rotating
  - Carefully spread the spools apart slightly to correct

```python
hall_reading(digit, 1, 4)
```

### Hall Readings
The display rotates 10 times (alter as needed) display the number of positive (and negative) magnet reads after each rotation.
- Look for consistency in the number of positive reads
- Home position should be somewhere within these positive reads
- Current home position value is 90 - this is sufficient to move past the first magnet read but does not advance past the first card
- At this step, just establish a range of positive magnet reads to work with
- Continue to watch that cards fall as desired and make note of any cards for a late test (see Display Characters)

```python
hall_reading(digit, 10)
```

### Configure Home
The display is advanced to the first magnet read and then advanced slowly printing each step. Use this to help determine the Home position, modify the configuraiton value for home reads as appropriate. Then uncomment and use the go_home function to test any modified values.

```python
configure_home(digit)
# digit.go_home()   # Set the Home Reads variable and test setting
```

### Display Characters
Use this section to display specific digits/characters.
- Go to any cards that are sticking to make adjustments as needed
- Test responsiveness of going to a character, pausing, and then displaying other characters

```python
# digit.display_character('1-AM')   # Display a single character
# Modify the following show list as desired to move between characters
# show = ['3','7',' ','2','0','6']
show = ['2-PM','6-AM','0-PM']
for d in show:
   digit.display_character(d)
   time.sleep(1)
```

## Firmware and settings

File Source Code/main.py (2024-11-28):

import asyncio
from button import Button
from config import Config
from display import Display
from jmbtime import JMBTime
from led import LED
from log import Log
from timer import Timer
from wifi import WIFI
from wifiap import WIFIAP

########## Global Methods

def current_state():
    """
    Checks the global tasks and returns the current state of the program

    Returns (int):
        1: Idle - No global task is currently running
        2: Config - Configuration mode is running
        3: Set DateTime - Set Date Time mode, using NTP if configured and running Display Update mode
    """
    global task_config
    global task_setdt

    if task_setdt != None and not task_setdt.done():
        return 3
    elif task_config != None and not task_config.done():
        return 2
    else:
        return 1
    
########## Waiters and Timers

async def timer_display_update():
    """
    Ensures the display is updated every minute
    """
    global jmbtime
    global task_display_update
    
    while True:
        # Run Display Update mode (if not currently running)
        sleep_sec = 60
        if task_display_update == None or task_display_update.done():
            task_display_update = asyncio.create_task(display_update_mode())
            await task_display_update
            dt = jmbtime.get_localtime()
            sleep_sec = 60 - dt[6]

        # Wait for the next minute occurrance
        await asyncio.sleep(sleep_sec)

async def waiter_timer_setdt():
    """
    Respond to the timer event to trigger Set Date Time mode
    """
    global event_timer_setdt
    global task_setdt

    while True:
        # Wait for the timer event
        await event_timer_setdt.wait()

        # Event has been triggered, check state of program
        if current_state() == 1:
            # Create the Set Date Time task
            task_setdt = asyncio.create_task(setdt_mode())

        # Reset the event
        event_timer_setdt.clear()

async def waiter_btn_config_click():
    """
    Respond to single button click: Enter Config mode
    """
    global event_btn_config_click
    global task_config

    while True:
        # Wait for the button click
        await event_btn_config_click.wait()

        # Check current program state (only execute if Idle)
        if current_state() == 1:
            # Create the config task
            task_config = asyncio.create_task(config_mode())
        
        # Reset the event
        event_btn_config_click.clear()

async def waiter_btn_config_cancel_click():
    """
    Respond to long button click: Cancel Config mode
    """
    global event_btn_config_cancel_click
    global task_config

    while True:
        # Wait for the long button click
        await event_btn_config_cancel_click.wait()

        # Check current program state (only execute if Config is running)
        if current_state() == 2:
            # Cancel the task (assume cancellation, LED will turn off when completed)
            _ = task_config.cancel()
    
        # Clear the event to wait for the next long click
        event_btn_config_cancel_click.clear()

async def waiter_btn_setdt_click():
    """
    Respond to single button click: Set Date and Time and display
    """
    global event_btn_setdt_click
    global task_setdt

    while True:
        # Wait for the button click
        await event_btn_setdt_click.wait()

        # Check program state (only execute if idle)
        if current_state() == 1:
                # Create the setdt task
                task_setdt = asyncio.create_task(setdt_mode())

        # Reset the event
        event_btn_setdt_click.clear()

async def waiter_btn_setdt_cancel_click():
    """
    Respond to long button click: Cancel Set Date Time mode
    """
    global event_btn_setdt_cancel_click
    global task_setdt

    while True:
        # Wait for the long button click
        await event_btn_setdt_cancel_click.wait()

        # Check if the Set Date Time task is running (Program State = 3)
        if current_state() == 3:
            # Cancel the event (assume cancellation, LED will shut off when complete)
            task_setdt.cancel()

        # Clear the event to wait for the next long click
        event_btn_setdt_cancel_click.clear()

########## Modes

async def config_mode():
    """
    Main method for configuration mode
    """
    global config
    global jmbtime
    global led
    global wifiap
    global wifi

    # Main code
    try:
        # Set light blinking to indicate config mode is starting
        led.blink_constant()

        # Disconnect wifi (only disconnects if currently connected)
        wifi.disconnect()

        # Start the server
        await wifiap.start_server(print_status=True)

        # Wait for Exit event
        await event_config_exit.wait()

        # User is done
        event_config_exit.clear()
        
    finally:
        # Code to execute even if task is canceled

        # Stop the server
        wifiap.stop_server()

        # Turn of the config light
        led.off()

        # Ensure the config object is updated with the latest config data
        config.read()

        # Ensure JMBTime has the correct Timezone offsets
        jmbtime.load_timezone_offset(config.timezone)


async def setdt_mode():
    """
    Updates the Real Time Clock (RTC) using the Network Time Protocol (NTP), if enabled, and then updates the display time
    """
    global jmbtime
    global led
    global task_display_update
    global wifi

    # Turn on the led
    led.on()

    # Is NPT mode enabled?
    if config.ntp_enabled == 1:
        # Start the log
        log = Log()
        log.write('Start the Set Date Time process', 'w')

        try:
            # Wifi Connection
            if not wifi.wlan.isconnected():
                # Attempt to connect
                if await wifi.connect(log) == "Failure":
                    # Error has been written to log, give the error blink code to the user, and exit
                    led.blink_error()
                    return

            # Set the Date Time
            await jmbtime.set_rtc_ntp()

        except asyncio.CancelledError:
            # Task was canceled
            log.write("User canceled Set Date Time process")
            led.blink_error()
            raise # Raise the error up
            
        except OSError as err:
            # Unknown error
            log.write(f'{err=}')
            raise

    # Update the display (if not already running)
    if task_display_update == None or task_display_update.done():
        task_display_update = asyncio.create_task(display_update_mode())
        await task_display_update
    
    # Turn off the led to indicate the mode is finished
    led.off()

async def display_update_mode():
    """
    Updates the display with the date and time as set in the Real Time Clock (RTC)
    """
    global display
    global jmbtime

    # Get the datetime tuple (year, month (1-12), day (1-31), weekday (0-6:Sun-Sat), hour (1-12), min (0-59), sec (0-59), meridiem (AM/PM))
    dt = jmbtime.get_localtime()

    # Update the display
    display.display_datetime(dt)
    # print(dt) # Debug line


########## Main Method
async def main():
    """
    Main program loop
    """
    global task_setdt
    global timer_setdt

    # Set the Date Time
    task_setdt = asyncio.create_task(setdt_mode())
    await task_setdt

    # Waiters and Timers
    asyncio.create_task(timer_display_update()) # This will update the display immediately again, however, the previous code should have already set the correcte date/time
    asyncio.create_task(waiter_timer_setdt())
    asyncio.create_task(waiter_btn_config_click())
    asyncio.create_task(waiter_btn_config_cancel_click())
    asyncio.create_task(waiter_btn_setdt_click())
    asyncio.create_task(waiter_btn_setdt_cancel_click())

    # Start the Set Date and Time Timer
    timer_setdt.start()

    # Infinite loop
    while True:
        # Ensure the program continues to run
        await asyncio.sleep(60)

#### Globals

# Events
event_timer_setdt = asyncio.Event()
event_btn_config_click = asyncio.Event()
event_btn_config_cancel_click = asyncio.Event()
event_btn_setdt_click = asyncio.Event()
event_btn_setdt_cancel_click = asyncio.Event()
event_config_exit = asyncio.Event() # Used in wifi app to indicate when user clicks Exit

# Objects
config = Config()
display = Display([15,14,13],[1,2,3,4,5])
timer_setdt = Timer(event_timer_setdt, 3600, 60) # One hour timer (3,600 seconds) wait 1 min (60 sec) between timer checks
btn_config = Button(18, event_btn_config_click, event_btn_config_cancel_click)
btn_setdt = Button(19, event_btn_setdt_click, event_btn_setdt_cancel_click)
jmbtime = JMBTime(config.timezone)
led = LED(16)
wifiap = WIFIAP(event_config_exit)
wifi = WIFI()

# Tasks
task_config = None
task_display_update = None
task_setdt = None

# Start the prgoram
try:
    asyncio.run(main())
except KeyboardInterrupt:
    # Ensure LED is off
    led.off()
finally:
    asyncio.new_event_loop()

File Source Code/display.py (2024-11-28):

# Used to display the desired date time
# Do not use asyncio to sleep for stepper motor
#   Requires microseconds, it doesn't appear this is recommended or possible with asyncio sleep/sleep_ms
# Flap Count Modify - this tag in code indicates a line of code that can be modified when testing fewer then 5 displays
from machine import Pin
from time import sleep_us

class Display:
    """
    Class for displaying desired digits

    Methods:
    display_datetime() - sets the split-flap displays to display the date and time

    Components:
        Stepper Motor (28BYJ-48)
        Driver Board (ULN2003)
        Hall effect sensor (A3144)
        8-bit Serial-In Parellel-Out (SIPO) Shift Register (74HC595)
    
    Pin Configuration:
        Stepper Motor connects to Driver Board
        Driver Board
            GND (-) > Ground pin
            VCC (+) > SysBus (5v) - assumes pico is powered by USB
            IN1-4 > Shift Register
        Shift Register
            1-7,15 QA-QH - driver boards (2 driver boards)
            8 GND > Ground
            9 QH' > Daisy chain > Shift Register 14 (serial input)
            10 SRCLR (shift register clear) - SysBus 5 Volts
            11 SRCLK "clock" (shift register clock) - GPIO (all shift registers use the same pin)
            12 RCLK "latch" (storage register clock) - GPIO (all shift registers use the same pin)
            13 OE (output enable) - Ground
            14 SER (serial input) - GPIO (first shift register goes to Pico pin, remaining are daisy chained)
            16 VCC - SysBus 5 volts
            Note: SysBus 5 Volts - used for simplicity since Driver Boards are connected to this
                Assumes Pico W is powered by USB
                HC595 can also be powered by 3.3V instead
                Daisy Chain example: GPIO > Shift Register 1 pin 14 (serial input) > Shift Register 1 pin 9 > Shift register 2 pin 14 > Shift 2 pin 9 > Shift 3 pin 14...
        Hall sensor
            GND (-) > Ground pin
            VC (+) > SysBus (5v)
            IN > Any GPIO - use Pin.PULL_UP
    """

    def __init__(self, pins_sr, pins_hall):
        """
        Initialize the display object

        pins_sr ([int,int,int]) - List of Pico GPIO pins the Shift Registers are connected to, in the following order:
            0 - Clock: Shift Register Clock (pin 11 on shift register)
            1 - Latch: Storage Register Clock (pin 12 on shift register)
            2 - Serial Input (pin 14 on shift register)
        
        pins_hall ([int,int,...]) - List of Pico GPIO pins the Hall sensors are connected to, 0 = left-most digit
        """
        ########## Set Pins

        # Hall Sensors (10)
        self.pins_hall = [Pin(pin_hall, Pin.IN, Pin.PULL_UP) for pin_hall in pins_hall]

        # Shift Register
        self.pin_clock = Pin(pins_sr[0], Pin.OUT)
        self.pin_latch = Pin(pins_sr[1], Pin.OUT)
        self.pin_serial = Pin(pins_sr[2], Pin.OUT)

        ########## Constants
            
        # Array of flaps - first value (index: 0) should be the Home character
        self.flap_values_digit = ['0','1','2','3','4','5','6','7','8','9',',',':','!',' ']
        self.flap_values_dow = ['0-AM','0-PM','1-AM','1-PM','2-AM','2-PM','3-AM','3-PM','4-AM','4-PM','5-AM','5-PM','6-AM','6-PM']

        # Number of split-flap displays
        self.display_count = 5 # Flap Count Modify
        self.shift_register_count = 3 # Flap Count Modify

        # Flap Value Current - the current index of the character displayed (If unknown or not set: None)
        self.flap_value_current = [None] * self.display_count

        # Flap Count - (Added to reduce redundant code: len function calls)
        self.flap_count = 14

        # Seq - Motor step sequence (order to set motor pins to rotate motor)
        #   Index 0 - sequence step
        #   Index 1 - 0 = no display turns, 1 = right-only, 2 = left-only, 3 = both turn
        self.seq = [[0,3,48,51],[0,6,96,102],[0,12,192,204],[0,9,144,153]]
        
        # Home Reads - Number of positive magnet reads to set as home position
        self.home_reads = 90

    def display_datetime(self, dt):
        """
        Rotates the displays to display the desired text

        dt (tuple) - (year, month (1-12), day (1-31), weekday (0-6:Sun-Sat), hour (1-12), min (0-59), sec (0-59), meridiem (AM/PM))
        """
        # Convert datetime elements to target index
        h = f'{dt[4]:2}'
        m = f'{dt[5]:02}'
        flap_0 = self.flap_values_digit.index(h[:1])
        flap_1 = self.flap_values_digit.index(h[1:])
        flap_2 = self.flap_values_digit.index(m[:1])
        flap_3 = self.flap_values_digit.index(m[1:])
        flap_4 = self.flap_values_dow.index(f'{dt[3]}-{dt[7]}') # Flap Count Modify
        self.flap_value_target = [flap_0,flap_1,flap_2,flap_3,flap_4] # Flap Count Modify

        # Initialize sequence index (0-3)
        seq_index = 0

        # Set maximum attempts to reach target characters (min of 2), expected possibilities for each flap:
        #   1) already at target (0 attempts)
        #   2) go to character (1 attempt)
        #   3) go home > go to character (2 attempts)
        #   4) Error finding character or home (3+ attempts)
        max_attempts = 3

        # Determine steps to turn each display to reach the desired value
        steps_remaining = [self._calculate_steps(i) for i in range(self.display_count)]
        steps_remaining.append(0) # Flap Count Modify: adds a dummy step for no 6th display

        # Start attempts
        while sum(map(abs, steps_remaining)) > 0 and max_attempts > 0:

            # Set maximum number of steps to prevent potentially endless running (1.25 revolutions 2048 + 512)
            steps_max = 2560

            # Advance Steps
            while sum(map(abs, steps_remaining)) > 0 and steps_max > 0:
                # Take a step
                bytes_seq = [self.seq[seq_index][(0 if steps_remaining[i] == 0 else 1) * 2 + (0 if steps_remaining[i+1] == 0 else 1)] for i in range(0, self.display_count, 2)]
                self._bytes_out(bytes_seq)

                # Determine Steps Remianing
                for i in range(self.display_count):
                    if steps_remaining[i] > 0:
                        # Decrement steps
                        steps_remaining[i] -= 1

                    elif steps_remaining[i] == -1:
                        # Determine if off magnet
                        if self.pins_hall[i].value() == 1:
                            # Find first magnet read
                            steps_remaining[i] = -2
                    
                    elif steps_remaining[i] == -2:
                        # Determine if magnet read
                        if self.pins_hall[i].value() == 0:
                            # Advance to home position
                            steps_remaining[i] = self.home_reads

                # Reduce maximum number of steps
                steps_max -= 1
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

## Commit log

2024-11-02 Split Flap Files
    [axel-holder.scad, axel-holder.stl, base.scad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]
2024-11-13 Assembly and code
2024-11-13 Create Display Assembly.md
2024-11-14 Update Display Assembly.md
2024-11-15 Assembly Flap Photos
2024-11-27 Create Electronic Wiring.md
2024-11-27 Update Electronic Wiring.md
2024-11-28 Wiring Test
